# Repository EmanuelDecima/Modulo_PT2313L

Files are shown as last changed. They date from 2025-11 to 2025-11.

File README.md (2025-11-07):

# Módulo de Procesamiento de Audio PT2313L
Módulo estéreo de control de volumen, tono, balance y loudness basado en el integrado PT2313L. Diseñado para aplicaciones de audio Hi-Fi y sistemas de sonido personalizados.

## 🔧 Características
- Control digital de volumen, tono, balance y loudness mediante bus I²C.
- Entradas de audio estéreo con selección de canal.
- Alimentación simple de 9–12 V DC.
- Pines de control compatibles con microcontroladores (Arduino, STM32, ESP32, etc.).
- PCB de simple faz, tamaño compacto (100 mm × 50 mm).
- Boneras para alimentación y salidas de audio
- Conector JST para entradas de audio
- Conector de 4 pines para comunicación mediante bus I²C.

## 🖼️ Esquema y PCB
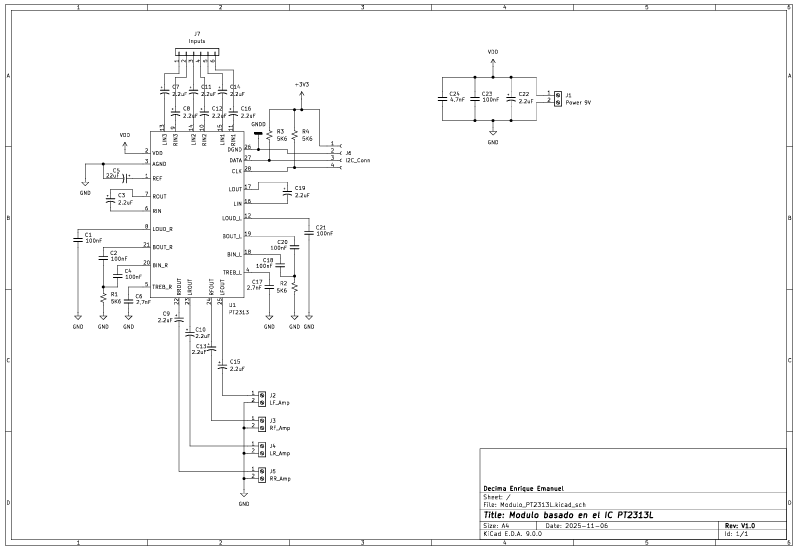
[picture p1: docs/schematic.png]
Esquemático del módulo

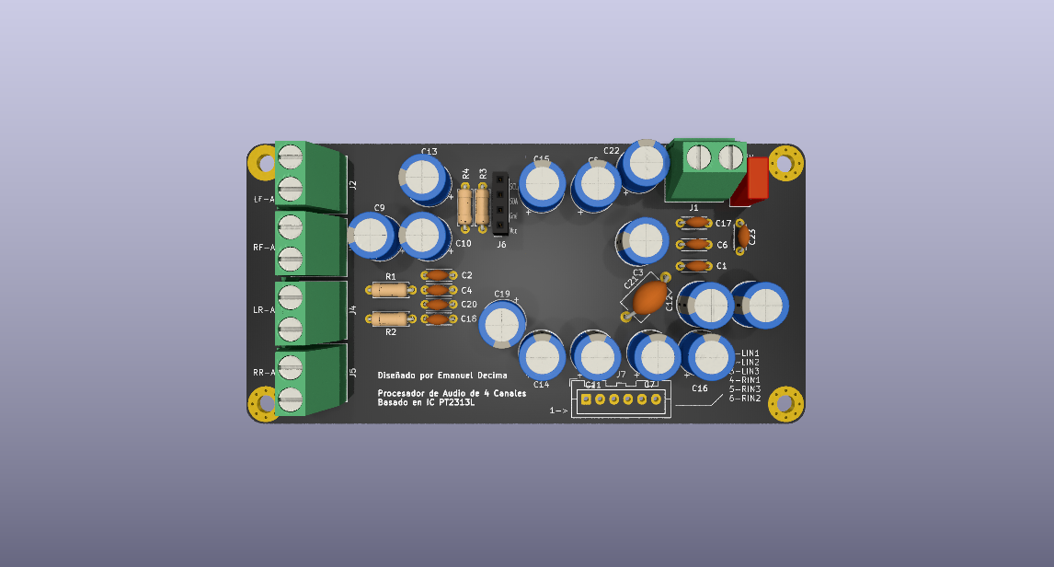
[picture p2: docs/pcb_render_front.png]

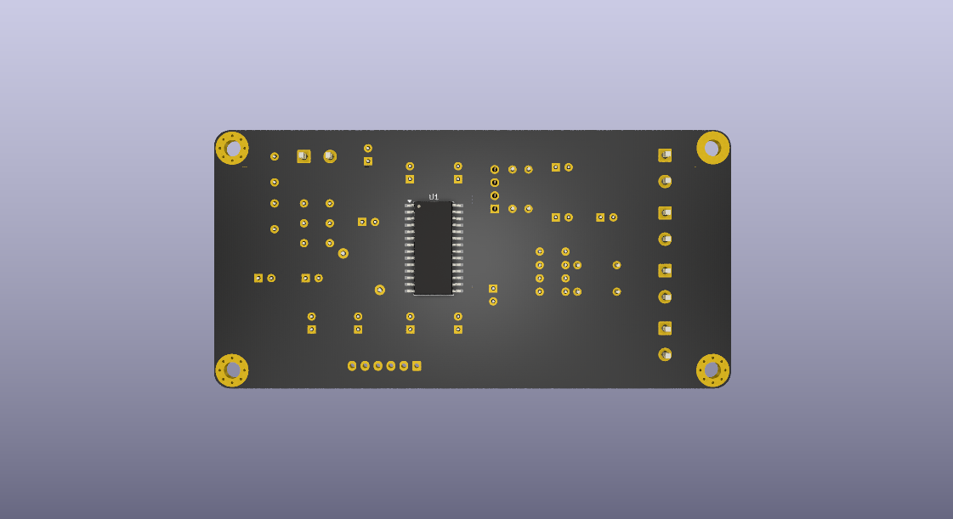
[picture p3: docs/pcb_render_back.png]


## ⚙️ Documentación técnica
El módulo está basado en el integrado **PT2313L**, un procesador de audio con control digital I²C.  
Las señales de audio ingresan a través de conectores JST y pasan por la etapa de selección y control del PT2313L antes de salir hacia el amplificador.  
Los niveles de volumen, balance y tono son programables por software.

## 🧰 Requisitos
- Controlador I²C (Arduino, STM32, ESP32, Raspberry Pi, etc.)
- Fuente de alimentación regulada 9–12 V DC
- Señal de audio de nivel de línea

## 🧠 Compatibilidad
Probado con:
- Arduino Nano / UNO
- STM32F103C8 ("Blue Pill")
- ESP32-WROOM

## 👤 Autor
Diseñado por Emanuel Décima  
📧 Contacto: emanueldecima3@gmail.com  
📅 Noviembre 2025

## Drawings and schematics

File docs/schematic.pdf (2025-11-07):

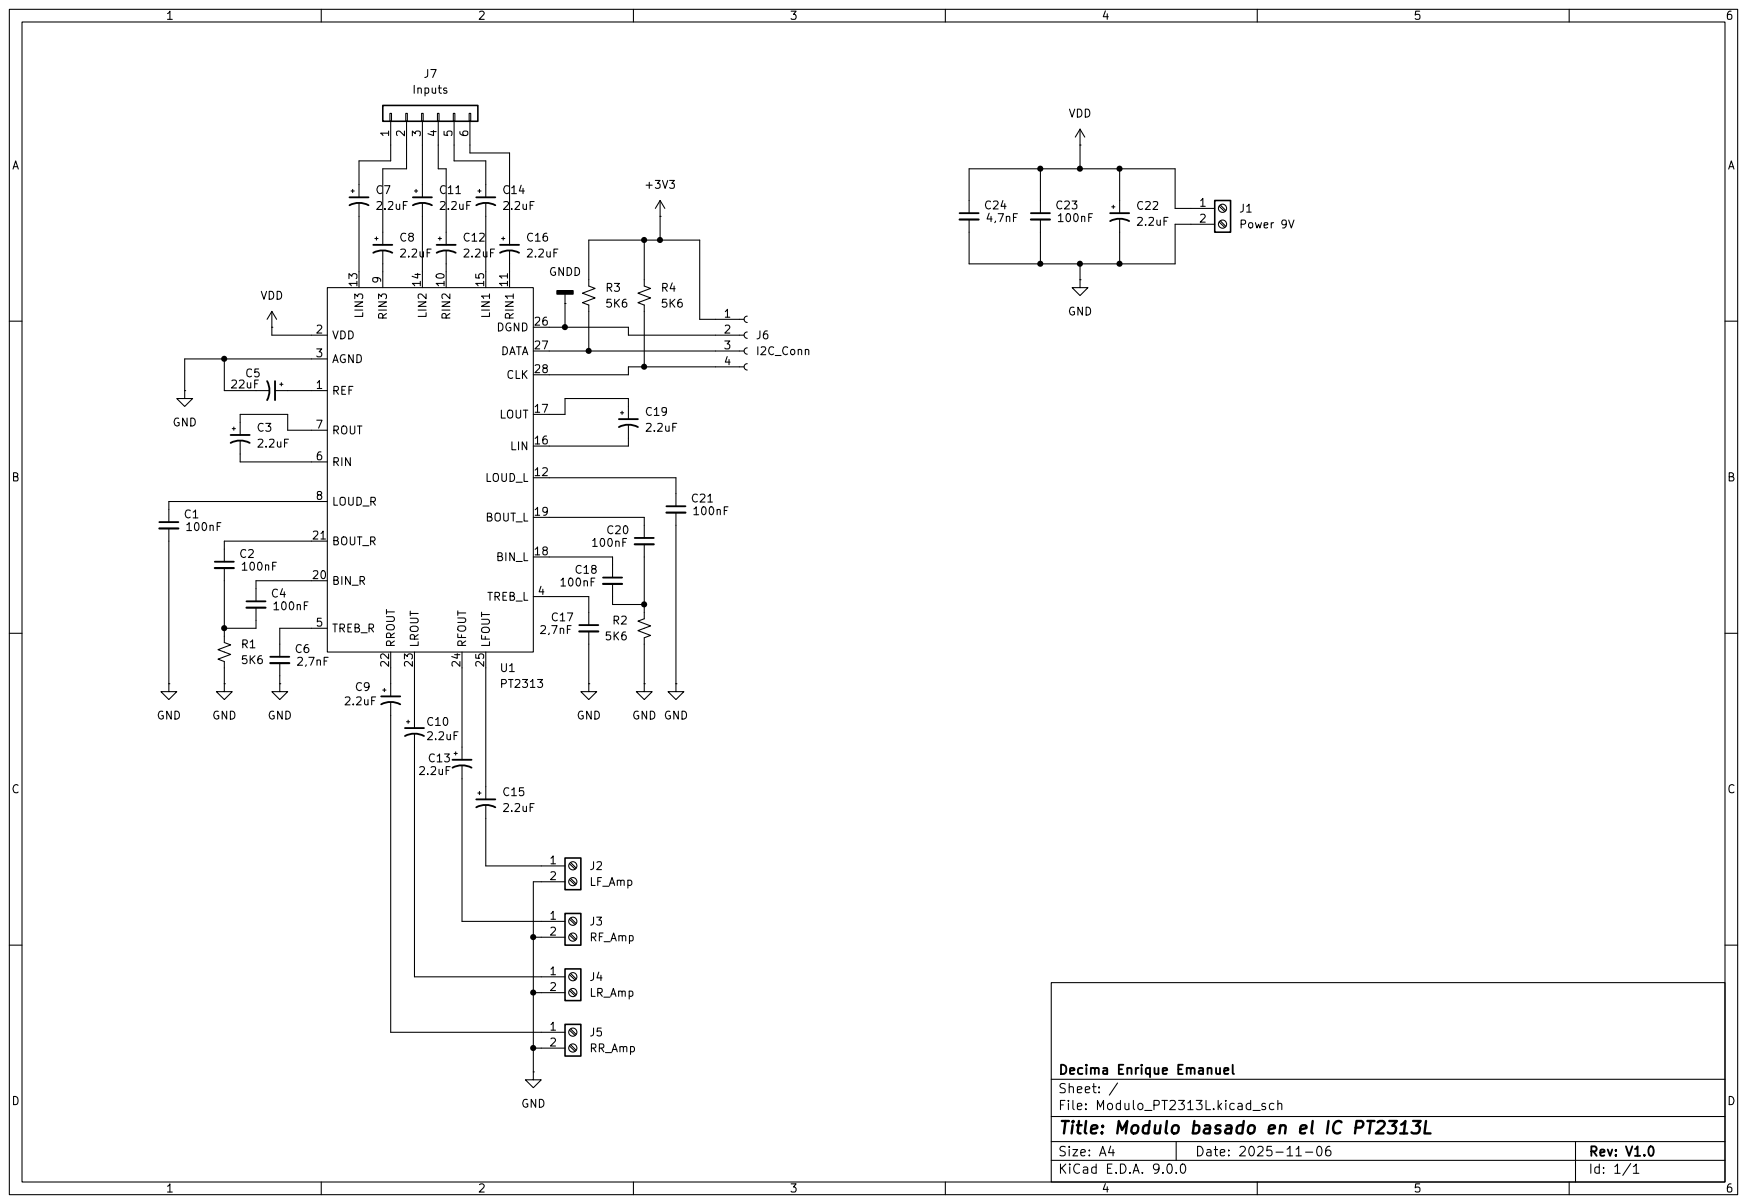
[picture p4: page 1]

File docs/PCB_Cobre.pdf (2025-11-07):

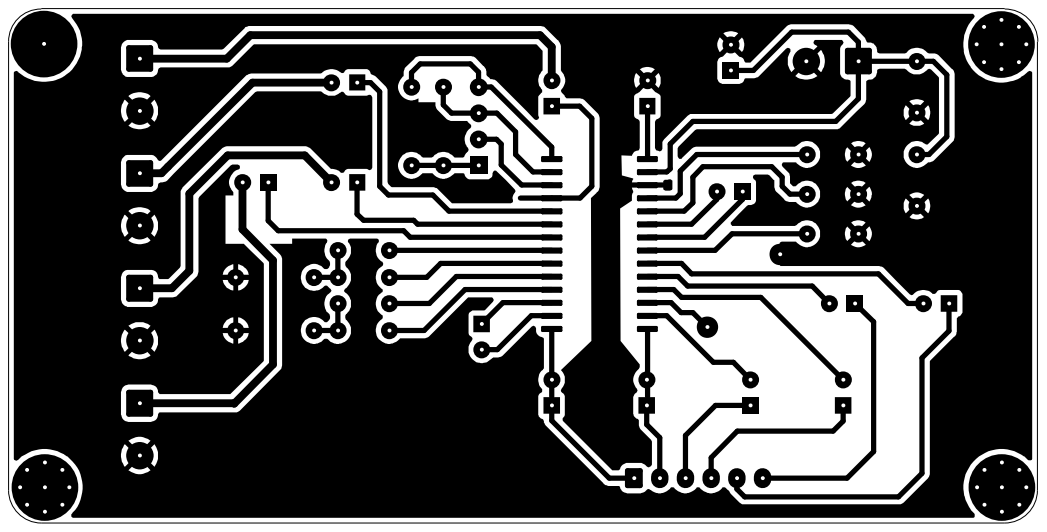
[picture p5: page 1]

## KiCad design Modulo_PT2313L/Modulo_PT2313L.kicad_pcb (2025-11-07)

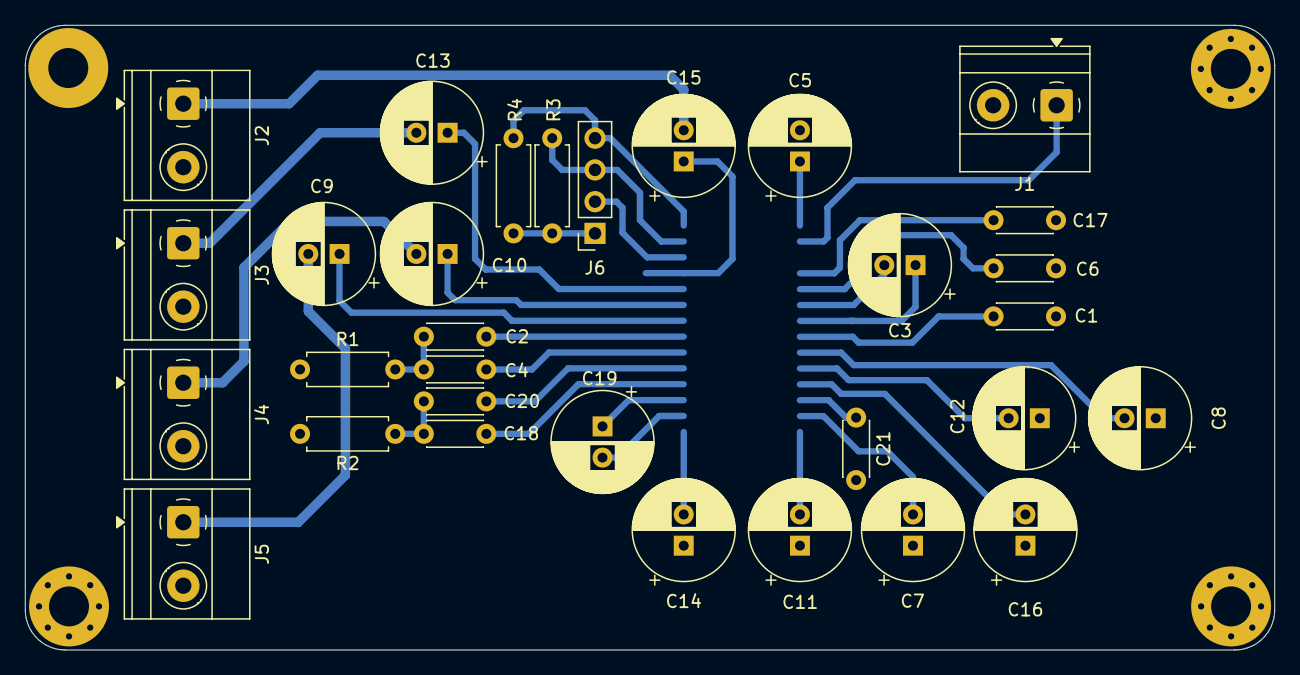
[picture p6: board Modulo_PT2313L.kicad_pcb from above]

Board: 2 copper layers, 100.0 x 50.0 mm, 32 parts (1 on the bottom side), 35 nets.

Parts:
C1, C2, C4, C18, C20, C21: 100nF; C_Disc_D4.3mm_W1.9mm_P5.00mm
C3, C7, C8, C9, C10, C11, C12, C13, C14, C15, C16, C19: 2.2uF; CP_Radial_D8.0mm_P2.50mm
C5: 22uF; CP_Radial_D8.0mm_P2.50mm
C6, C17: 2,7nF; C_Disc_D4.3mm_W1.9mm_P5.00mm
J1: Power 9V; TerminalBlock_Phoenix_MKDS-1,5-2-5.08_1x02_P5.08mm_Horizont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
J2: LF_Amp; TerminalBlock_Phoenix_MKDS-1,5-2-5.08_1x02_P5.08mm_Horizont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
J3: RF_Amp; TerminalBlock_Phoenix_MKDS-1,5-2-5.08_1x02_P5.08mm_Horizont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
J4: LR_Amp; TerminalBlock_Phoenix_MKDS-1,5-2-5.08_1x02_P5.08mm_Horizont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
J5: RR_Amp; TerminalBlock_Phoenix_MKDS-1,5-2-5.08_1x02_P5.08mm_Horizont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
J6: Conn_01x04_Socket; PinSocket_1x04_P2.54mm_Vertical
R1, R2, R3, R4: 5K6; R_Axial_DIN0207_L6.3mm_D2.5mm_P7.62mm_Horizontal
U1: PT2313; SOIC-28W_7.5x17.9mm_P1.27mm

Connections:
+3V3: J6.1, R3.1, R4.1
GND: C1.2, C5.2, C6.2, C17.2, C21.2, J1.2, J2.2, J3.2, J4.2, J5.2, R1.2, R2.2, U1.3 (AGND)
GNDD: J6.2, U1.26 (DGND)
unnamed: C2.2, C4.2, R1.1
unnamed: C18.2, C20.2, R2.1
unnamed: C15.2, J2.1
unnamed: C13.2, J3.1
unnamed: C10.2, J4.1
unnamed: C9.2, J5.1
unnamed: J6.3, R3.2, U1.27 (DATA)
unnamed: J6.4, R4.2, U1.28 (CLK)
unnamed: C18.1, U1.18 (BIN_L)
unnamed: C4.1, U1.20 (BIN_R)
unnamed: C20.1, U1.19 (BOUT_L)
unnamed: C2.1, U1.21 (BOUT_R)
unnamed: C15.1, U1.25 (LFOUT)
unnamed: C14.2, U1.15 (LIN1)
unnamed: C11.2, U1.14 (LIN2)
unnamed: C7.2, U1.13 (LIN3)
unnamed: C19.2, U1.16 (LIN)
unnamed: C21.1, U1.12 (LOUD_L)
unnamed: C1.1, U1.8 (LOUD_R)
unnamed: C19.1, U1.17 (LOUT)
unnamed: C10.1, U1.23 (LROUT)
unnamed: C5.1, U1.1 (REF)
unnamed: C13.1, U1.24 (RFOUT)
unnamed: C16.2, U1.11 (RIN1)
unnamed: C12.2, U1.10 (RIN2)
unnamed: C8.2, U1.9 (RIN3)
unnamed: C3.2, U1.6 (RIN)
unnamed: C3.1, U1.7 (ROUT)
unnamed: C9.1, U1.22 (RROUT)
unnamed: C17.1, U1.4 (TREB_L)
unnamed: C6.1, U1.5 (TREB_R)
VDD: J1.1, U1.2 (VDD)

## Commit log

2025-11-06 primer commit
    [Modulo_PT2313L.kicad_pcb, Modulo_PT2313L.kicad_sch]
2025-11-07 PCB Diseñado
    [Modulo_PT2313L.kicad_pcb, Modulo_PT2313L.kicad_sch]
2025-11-07 agrego imagenes y esquematico
    [Modulo_PT2313L.kicad_sch]
2025-11-07 Replace PCB images with front and back views
    Updated PCB design images in README.
2025-11-07 Change schematic image from PDF to PNG format
    Updated schematic image format from PDF to PNG.
2025-11-07 cambio imagen de esquematico a png
